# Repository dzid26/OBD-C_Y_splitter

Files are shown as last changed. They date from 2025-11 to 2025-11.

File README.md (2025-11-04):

# OBD-C Y-splitter
- compact size - 1x2.5cm
- possibility to add 120ohm CAN termination on CAN1 and CAN3 (note they can flip, so always terminate both)
- test points for sbu1 and sbu2



### Arrangement:
- Female-Male-Female - harness box has to be connected to J1 (as indicated by the arrow's origin)



Schematic:


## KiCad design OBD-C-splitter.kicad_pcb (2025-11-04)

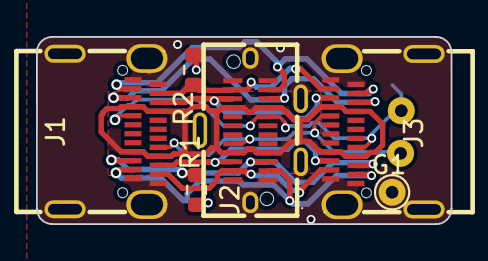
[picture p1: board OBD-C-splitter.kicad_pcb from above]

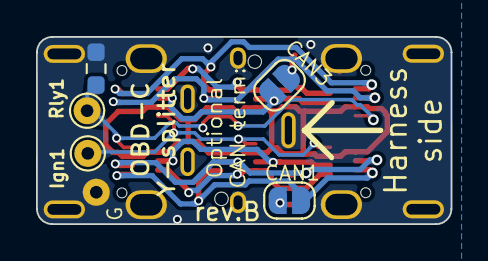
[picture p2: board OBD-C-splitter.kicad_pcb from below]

Board: 2 copper layers, 23.0 x 10.4 mm, 11 parts (5 on the bottom side), 14 nets.

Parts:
CAN1, CAN3: SolderJumper_2_Open; SolderJumper-2_P1.3mm_Open_RoundedPad1.0x1.5mm
G1: TestPoint; TestPoint_THTPad_D1.5mm_Drill0.7mm
Ign1: TestPoint; TestPoint_THTPad_D1.5mm_Drill0.7mm
J1, J3: Type-C Receptacle; TYPE-C-SMD_C9900025773
J2: Type-C Plug; USB-C-SMD_TYPEC-952-ACP24
R1, R2: 120R; R_0603_1608Metric
R3: 200; R_0603_1608Metric_Pad0.98x0.95mm_HandSolder
Rly1: TestPoint; TestPoint_THTPad_D1.5mm_Drill0.7mm

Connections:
/Sbu1: J1.B8 (SBU2), J2.B8 (SBU2), J3.A8 (SBU1), R3.1, Rly1.1
/Sbu2: Ign1.1, J1.A8 (SBU1), J2.A8 (SBU1), J3.B8 (SBU2)
/VBUS: J1.A4 (VBUS), J1.A9 (VBUS), J1.B4 (VBUS), J1.B9 (VBUS), J2.A4 (VBUS), J2.A9 (VBUS), J2.B4 (VBUS), J2.B9 (VBUS), J3.A4 (VBUS), J3.A9 (VBUS), J3.B4 (VBUS), J3.B9 (VBUS)
CAN0_H: J1.B11 (RX1+), J2.B11 (RX1+), J3.A2 (TX1+)
CAN0_L: J1.B10 (RX1-), J2.B10 (RX1-), J3.A3 (TX1-)
CAN1_H: CAN1.2 (B), J1.B2 (TX2+), J2.B2 (TX2+), J3.A11 (RX2+)
CAN1_L: J1.B3 (TX2-), J2.B3 (TX2-), J3.A10 (RX2-), R1.2
CAN2_H: J1.A11 (RX2+), J2.A11 (RX2+), J3.B2 (TX2+)
CAN2_L: J1.A10 (RX2-), J2.A10 (RX2-), J3.B3 (TX2-)
CAN3_H: J1.A2 (TX1+), J2.A2 (TX1+), J3.B11 (RX1+), R2.1
CAN3_L: CAN3.1 (A), J1.A3 (TX1-), J2.A3 (TX1-), J3.B10 (RX1-)
GND: G1.1, J1.A1 (GND), J1.A12 (GND), J1.B1 (GND), J1.B12 (GND), J1.S1 (SHIELD), J2.A1 (GND), J2.A12 (GND), J2.B1 (GND), J2.B12 (GND), J2.S1 (SHIELD), J3.A1 (GND), J3.A12 (GND), J3.B1 (GND), J3.B12 (GND), J3.S1 (SHIELD), R3.2
unnamed: CAN1.1 (A), R1.1
unnamed: CAN3.2 (B), R2.2

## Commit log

2025-10-07 added direction arrow
    [OBD-C-splitter.kicad_pcb]
2025-10-29 Order matters
    [OBD-C-splitter.kicad_sch]
2025-11-04 Fixed CAN labels and termination resistors and sbu
    [OBD-C-splitter.kicad_pcb, OBD-C-splitter.kicad_sch]
